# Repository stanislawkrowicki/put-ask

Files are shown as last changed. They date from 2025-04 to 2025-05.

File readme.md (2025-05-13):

# 🛠️ PepeBoy

**Portable GameBoy style console. Based on ESP32 microprocessor, 2.8" TFT display, WiFi** 

---

## 📌 Table of Contents
- [🎯 Project Goal](#-project-goal)
- [🔧 Hardware Design](#-hardware-design)
- [💻 Usage](#-usage)
- [🔧 Execution REV1](#-execution)

---

## 🎯 Project Goal

Portable and pocket size console, able to load games from external sd card. Possibility of on-line gameplay via Wi-Fi. Custom PCB board, self-made using CNC milling and UV solder mask paint; 3D printed case.

## 🔧 Hardware Design
The PCB was designed to be produced using a double-sided FR4 PCB blank. Unfortunately, due to the process, every via had to be soldered using copper wire. 

### ESP32 pinout description
#### buttons 
| Button | Switch id | GPIO  |
|:---:|:---:|:-----:|
| Right Button| SW_7 | IO35  |
| Left Button | SW_5 | IO27  |
| Up Button | SW_4 | IO33  |
| Down Button | SW_6 | IO34  |
| A Button | SW_8 | IO14  |
| B Button | SW_3 | IO32  |

#### touch 

| Touch Signal  | Description | GPIO  |
|:---:|:---:|:-----:|
| MISO | Master In Slave Out | IO19  |
| MOSI | Master Out Slave In | IO23  |
| CLK | Clock | IO18  |
| CS_T | Chip Select | IO4 |
| T_IRQ | Interrupt Handling | IO13  |

#### display
| Display Signal | GPIO  | Description |
|:---:|:-----:|:---:|
| SPI_CS | IO21  | Display Chip Select |
| SPI_MOSI | IO23  | Master Out Slave In (data) |
| SPI_MISO | IO19  | Master In Slave Out (data) |
| SPI_CLK | IO18  | Clock signal |
| D_DC | IO16  | Data/Command control |
| D_RST | IO17  | Display reset signal |
| D_LED | IO22  | Display backlight control |
#### SD card

| SD Signal  | GPIO  | Description |
|:---:|:-----:|:---:|
| SD_CS | IO25  | Chip Select karty SD |
| SD_CLK | IO18  | Clock signal |
| SD_MISO | IO19  | Master In Slave Out (data)  |
| SD_MOSI | IO23  | Master Out Slave In (data)  |

#### onePixel 2x2 led matrix
|2x2 LED signal|GPIO|Description|
|:--:|:--:|:--:|
|LED_DIN| IO26|Data in|

####  general SPI
| SPI Signal | GPIO  |
|:---:|:-----:|
| MISO | IO19  |
| MOSI | IO23  |
| CLK | IO18  |

<p align="center">
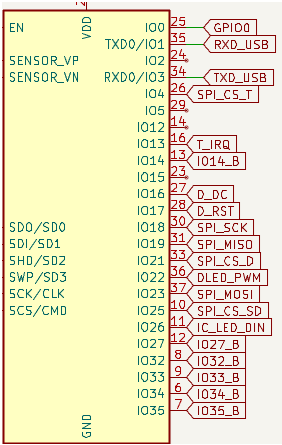
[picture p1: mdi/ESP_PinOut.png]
ESP pinout form KiCad
  
</p>
<!-- <p align="center">
  <img src="mdi/schem_all.jpg" alt="schematic of all" width="1000">
</p> -->

### Power Management Unit (IP5306) 
#### read execution paragraph !!!!
The console can be powered remotely using, for example, a 18650 Li-ion battery. Plugging the console into external power through USB-C will power the device and charge the battery. The IP5306 is used according to the typical application from the [datasheet](https://www.datasheetcafe.com/wp-content/uploads/2020/07/IP5306.pdf). We used a one-LED configuration and skipped the KEY_LED (D5 on the datasheet).

<p align="center">
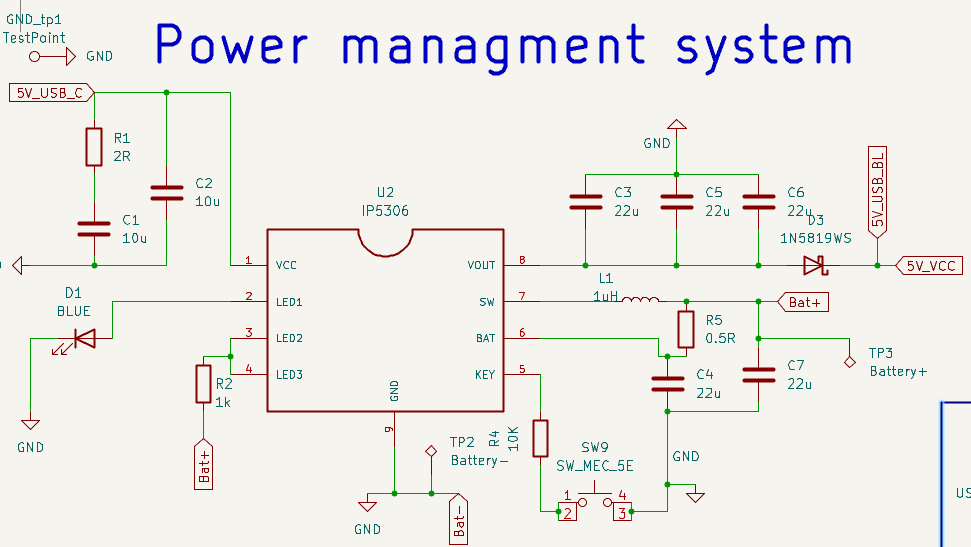
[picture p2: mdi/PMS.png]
  
</p>

## 💻 Usage

Description of how to use the project, e.g., how to start it, available modes, etc.

## 🔧 Execution
The PCB has been *mostly* successfully produced. We will leave a few notes describing our conclusions about what went wrong and what met or exceeded our expectations.

- Power Management Unit Failure: To be honest, I still don’t know exactly what went wrong. The design followed the datasheet, but the IC consistently failed, producing enough heat to desolder itself. After several attempts and considering the project deadline, I abandoned the idea of a remote power supply. If I were to do this again, I’d design a separate board dedicated solely to power management.

- Input-Only Pins (IO35, IO34): These pins lack internal pull-up resistors, and I neglected to include external ones in the design.

- WS2812 Segment Issue: This one’s due to a simple oversight: the collector of the Q1 transistor isn’t pulled up to 5V, which prevents proper operation of the LED segment.

- USB-C Port Soldering Difficulty: The mounting pads for the USB-C connector are too small, making the socket difficult to solder reliably. Larger pads would have made assembly easier.

---

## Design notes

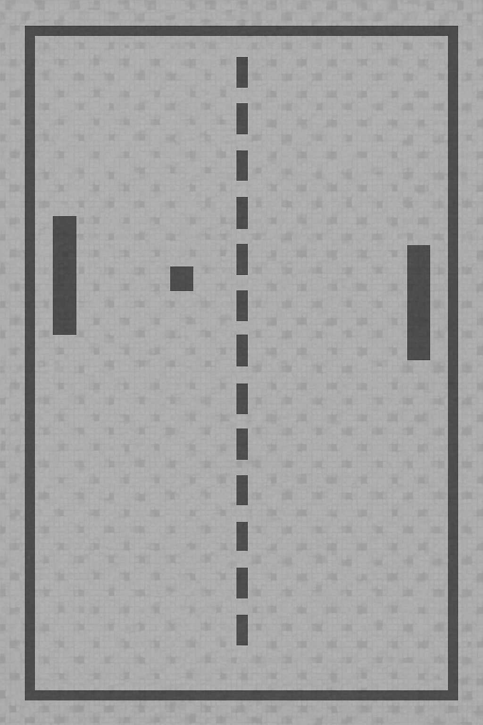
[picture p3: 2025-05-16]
pepelauncher/web/img/games/example.png

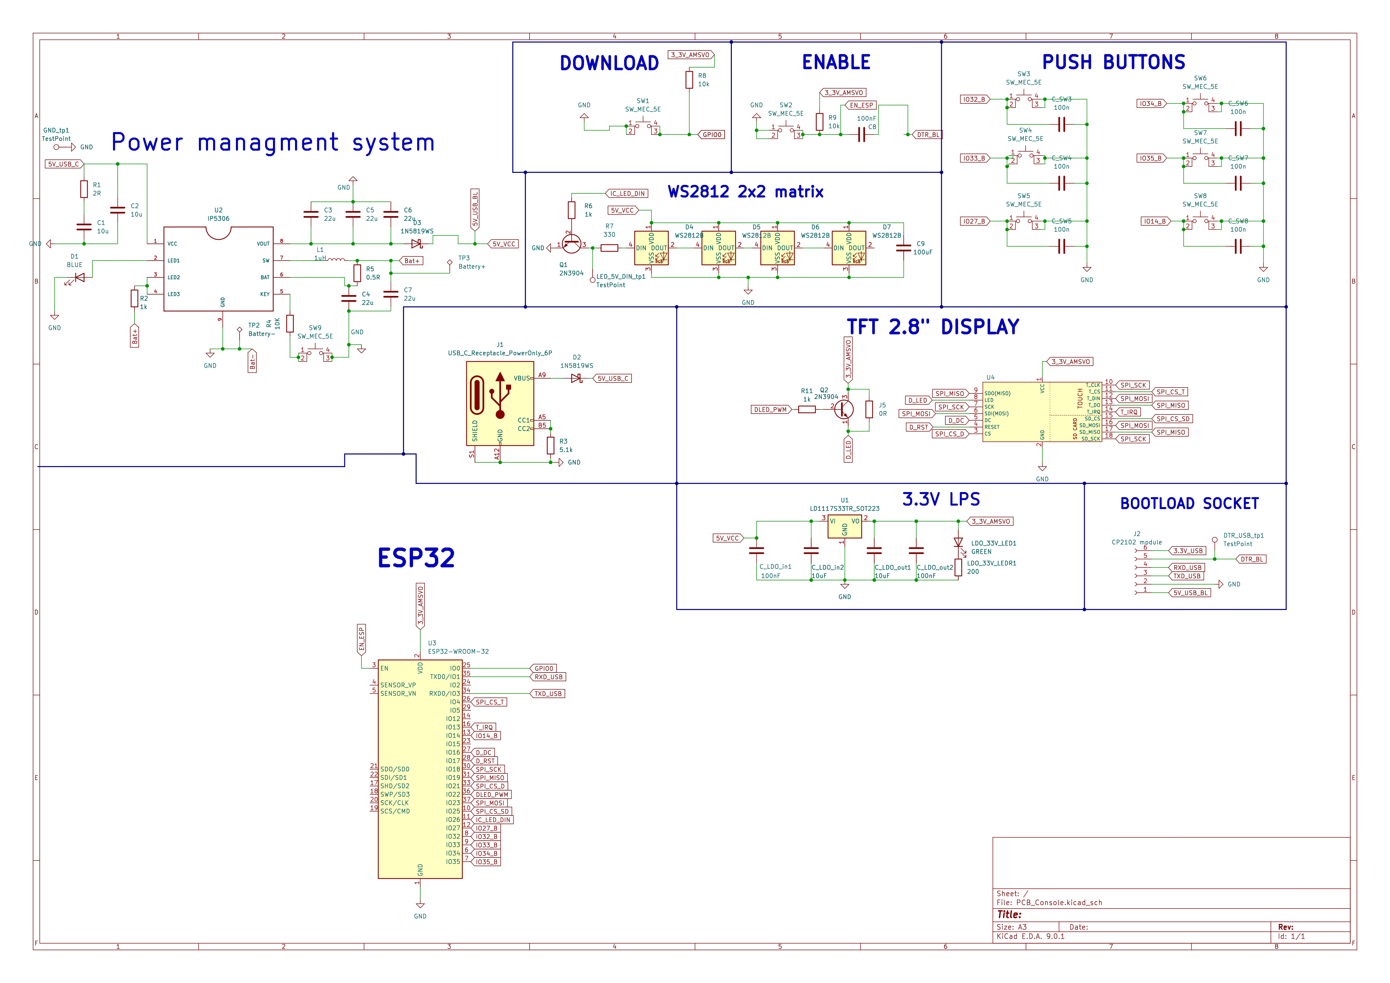
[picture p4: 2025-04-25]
mdi/schem_all.jpg

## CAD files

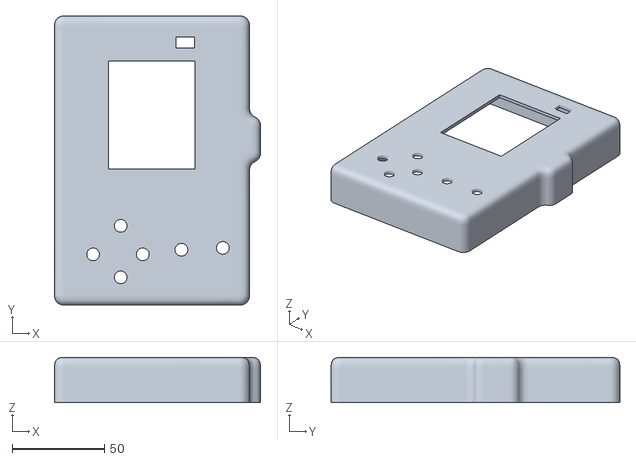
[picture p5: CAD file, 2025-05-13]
hardware/case/top_and_sides.stl
112.0 x 157.0 x 24.7

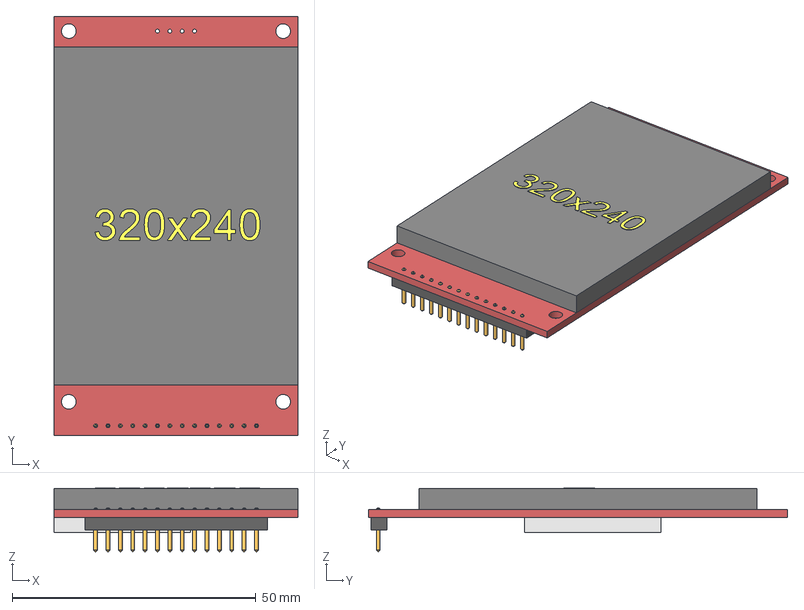
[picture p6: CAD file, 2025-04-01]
hardware/components_lib/TFT_320x240_touch_r0.step
50.0 x 86.0 x 13.1 mm
Body-header
Body-pins
Body-display
Body-sdcard
Body-board

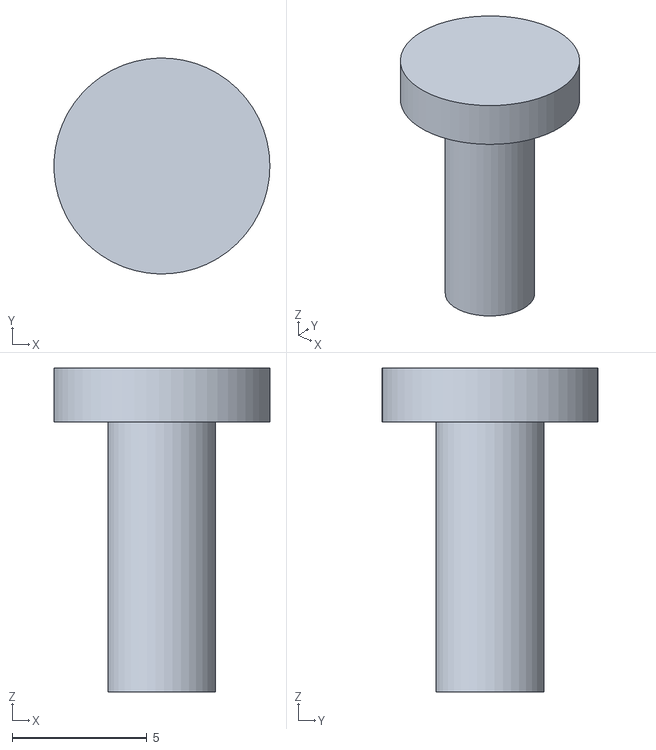
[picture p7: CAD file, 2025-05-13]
hardware/case/KeyCap.stl
7.99 x 8.00 x 12.0

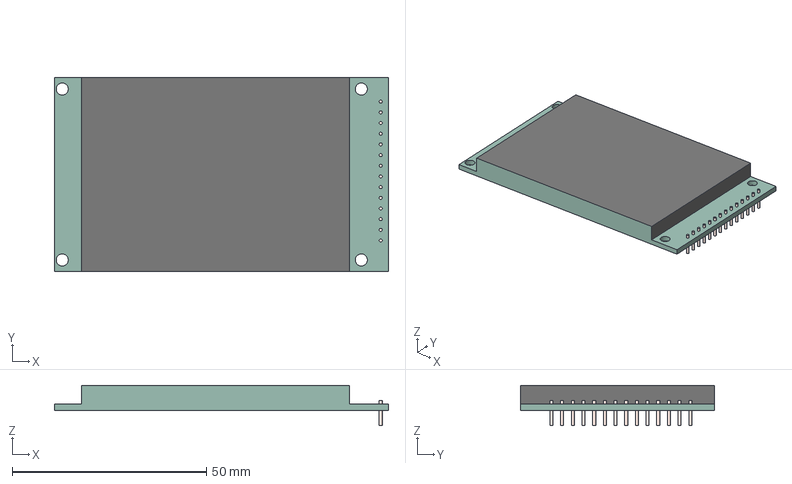
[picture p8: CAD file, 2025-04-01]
hardware/components_lib/TFT ILI9341.step
86.0 x 50.0 x 10.3 mm

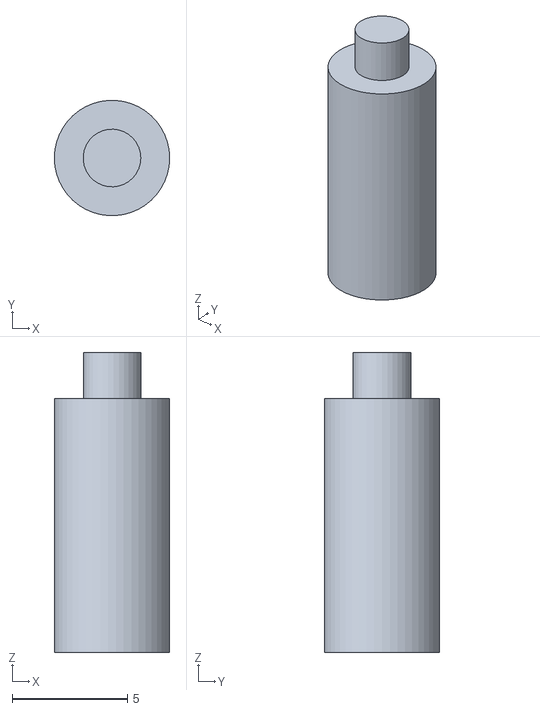
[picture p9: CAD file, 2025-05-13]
hardware/case/TFT_support.stl
5.00 x 4.99 x 13.0

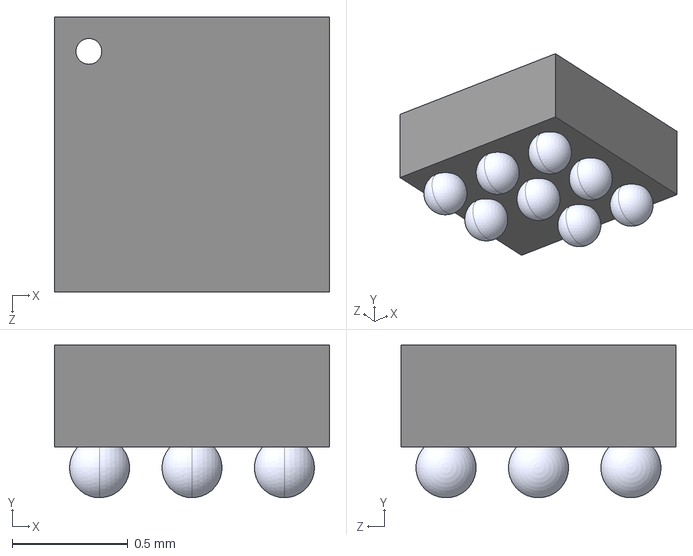
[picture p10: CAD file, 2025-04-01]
hardware/components_lib/IP5306.step
1.19 x 0.66 x 1.19 mm

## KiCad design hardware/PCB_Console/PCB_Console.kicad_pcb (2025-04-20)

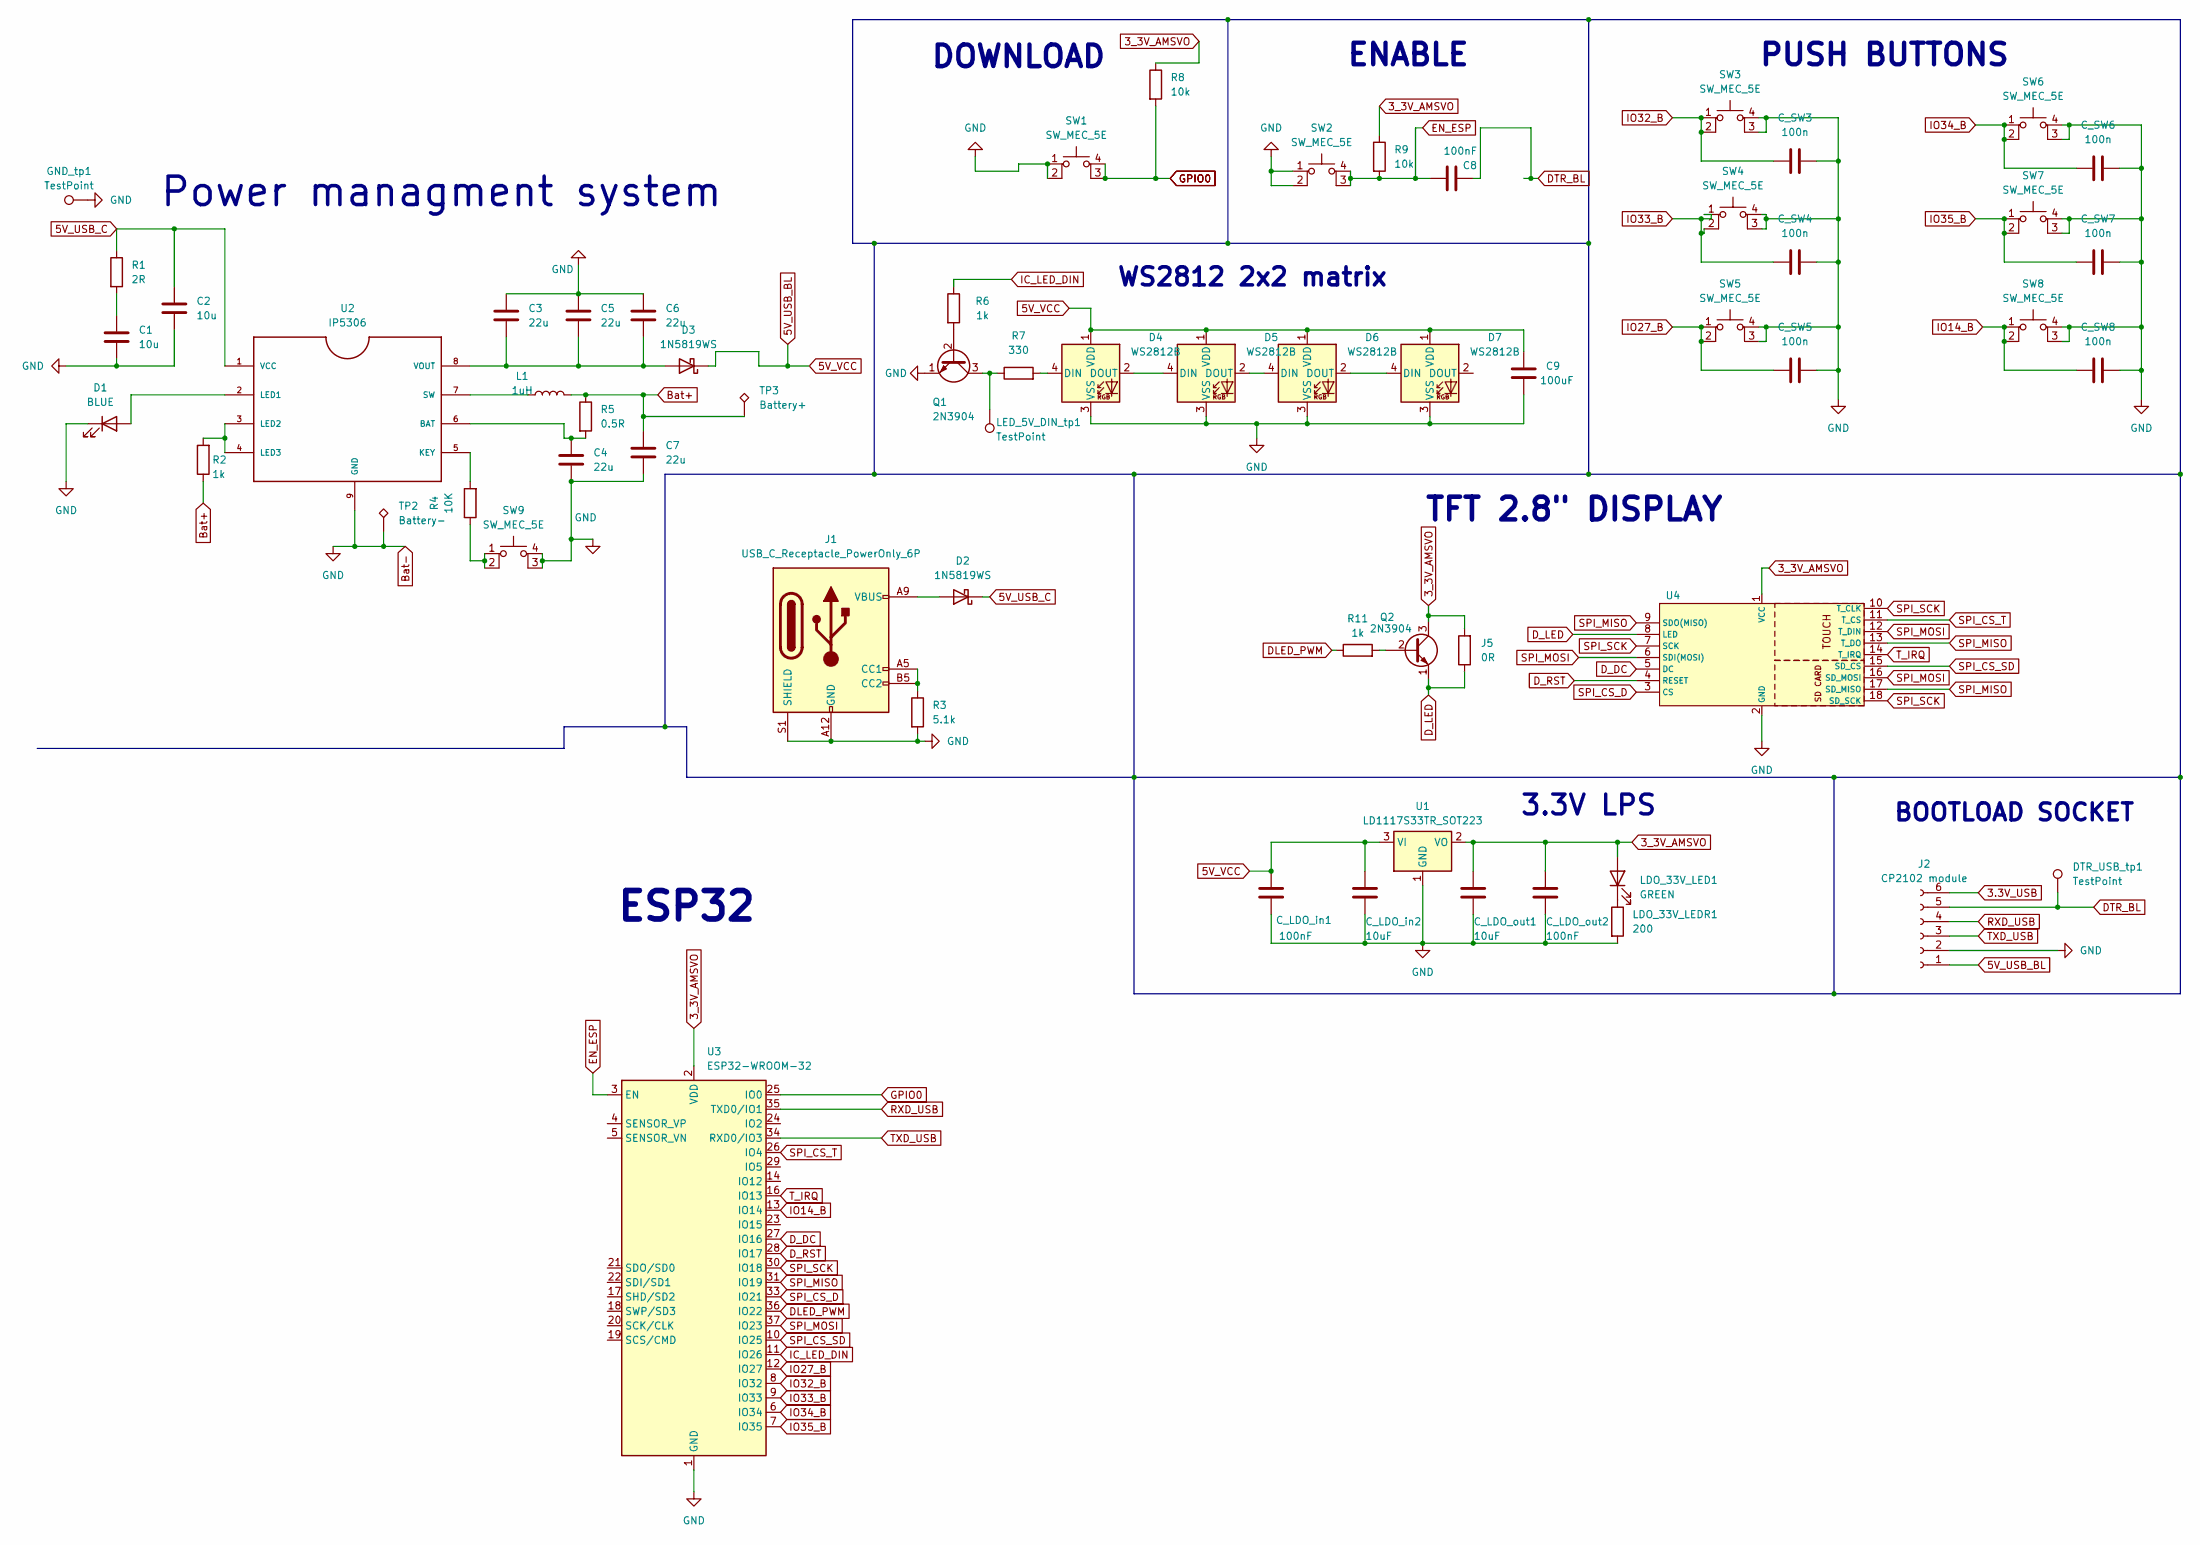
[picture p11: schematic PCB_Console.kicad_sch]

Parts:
C1, C2: 10u; C_1206_3216Metric_Pad1.33x1.80mm_HandSolder
C3, C4, C5, C6, C7: 22u; C_1206_3216Metric_Pad1.33x1.80mm_HandSolder
C8: 100nF; C_1206_3216Metric_Pad1.33x1.80mm_HandSolder
C9: 100uF; C_1206_3216Metric_Pad1.33x1.80mm_HandSolder
C_LDO_in1: 100nF; C_1206_3216Metric_Pad1.33x1.80mm_HandSolder
C_LDO_in2: 10uF; C_1206_3216Metric_Pad1.33x1.80mm_HandSolder
C_LDO_out1: 10uF; C_1206_3216Metric_Pad1.33x1.80mm_HandSolder
C_LDO_out2: 100nF; C_1206_3216Metric_Pad1.33x1.80mm_HandSolder
C_SW3, C_SW4, C_SW5, C_SW6, C_SW7, C_SW8: 100n; C_1206_3216Metric_Pad1.33x1.80mm_HandSolder
D1: BLUE; LED_D5.0mm
D2, D3: 1N5819WS; D_0805_2012Metric_Pad1.15x1.40mm_HandSolder
D4, D5, D6, D7: WS2812B; LED_WS2812B_PLCC4_5.0x5.0mm_P3.2mm
DTR_USB_tp1: TestPoint; TestPoint_Pad_D1.0mm
GND_tp1: TestPoint; TestPoint_Pad_D1.5mm
J1: USB_C_Receptacle_PowerOnly_6P; USB_C_Receptacle_GCT_USB4125-xx-x-0190_6P_TopMnt_Horizontal
J2: CP2102 module; PinSocket_1x06_P2.54mm_Vertical
J5: 0R; R_1206_3216Metric_Pad1.30x1.75mm_HandSolder
L1: 1uH; L_Chilisin_BMRB00060650
LDO_33V_LED1: GREEN; LED_D3.0mm
LDO_33V_LEDR1: 200; R_1206_3216Metric_Pad1.30x1.75mm_HandSolder
LED_5V_DIN_tp1: TestPoint; TestPoint_Pad_D1.0mm
Q1, Q2: 2N3904; TO-92_Wide
R1: 2R; R_1206_3216Metric_Pad1.30x1.75mm_HandSolder
R2, R6, R11: 1k; R_1206_3216Metric_Pad1.30x1.75mm_HandSolder
R3: 5.1k; R_1206_3216Metric_Pad1.30x1.75mm_HandSolder
R4: 10K; R_1206_3216Metric_Pad1.30x1.75mm_HandSolder
R5: 0.5R; R_1206_3216Metric_Pad1.30x1.75mm_HandSolder
R7: 330; R_1206_3216Metric_Pad1.30x1.75mm_HandSolder
R8, R9: 10k; R_1206_3216Metric_Pad1.30x1.75mm_HandSolder
SW1, SW2, SW9: SW_MEC_5E; SW_TS04-66-95-BK-100-SMT
SW3, SW4, SW5, SW6, SW7, SW8: SW_MEC_5E; SW_Push_12x12_aliexpress
TP2: Battery-; TestPoint_THTPad_D1.5mm_Drill0.7mm
TP3: Battery+; TestPoint_THTPad_D1.5mm_Drill0.7mm
U1: LD1117S33TR_SOT223; SOT-223-3_TabPin2
U2: IP5306; SOIC9P127_490X600X170L84X42T330X241N
U3: ESP32-WROOM-32
U4: TFT ILI9341

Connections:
3.3V_USB: J2.6
3_3V_AMSVO: C_LDO_out1.1, C_LDO_out2.1, J5.2, LDO_33V_LED1.2 (A), Q2.3 (C), R8.1, R9.1, U1.2 (VO), U3.2 (VDD), U4.1 (VCC)
5V_USB_BL: C9.2, C_LDO_in1.1, C_LDO_in2.1, D3.1 (K), D4.1 (VDD), D5.1 (VDD), D6.1 (VDD), D7.1 (VDD), J2.1, U1.3 (VI)
5V_USB_C: C2.1, D2.1 (K), R1.1, U2.1 (VCC)
Bat+: C7.1, L1.2, R2.1, R5.1, TP3.1
Bat-: C1.2, C2.2, C3.1, C4.2, C5.1, C6.1, C7.2, C9.1, C_LDO_in1.2, C_LDO_in2.2, C_LDO_out1.2, C_LDO_out2.2, C_SW3.1, C_SW4.1, C_SW5.1, C_SW6.1, C_SW7.1, C_SW8.1, D1.1 (K), D4.3 (VSS), D5.3 (VSS), D6.3 (VSS), D7.3 (VSS), GND_tp1.1, J1.A12 (GND), J1.B12 (GND), J1.S1 (SHIELD), J2.2, LDO_33V_LEDR1.2, Q1.1 (E), R3.2, SW1.1, SW1.2, SW2.1, SW2.2, SW3.3 (K), SW3.4 (A), SW4.3 (K), SW4.4 (A), SW5.3 (K), SW5.4 (A), SW6.3 (K), SW6.4 (A), SW7.3 (K), SW7.4 (A), SW8.3 (K), SW8.4 (A), SW9.3 (K), SW9.4 (A), TP2.1, U1.1 (GND), U2.9 (GND), U3.1 (GND), U3.15 (GND), U3.38 (GND), U3.39 (GND), U4.2 (GND)
DLED_PWM: R11.1, U3.36 (IO22)
DTR_BL: C8.2, DTR_USB_tp1.1, J2.5
D_DC: U3.27 (IO16), U4.5 (DC)
D_LED: J5.1, Q2.1 (E), U4.8 (LED)
D_RST: U3.28 (IO17), U4.4 (RESET)
EN_ESP: C8.1, R9.2, SW2.3 (K), SW2.4 (A), U3.3 (EN)
GPIO0: R8.2, SW1.3 (K), SW1.4 (A), U3.25 (IO0)
IC_LED_DIN: R6.1, U3.11 (IO26)
IO14_B: C_SW8.2, SW8.1, SW8.2, U3.13 (IO14)
IO27_B: C_SW5.2, SW5.1, SW5.2, U3.12 (IO27)
IO32_B: C_SW3.2, SW3.1, SW3.2, U3.8 (IO32)
IO33_B: C_SW4.2, SW4.1, SW4.2, U3.9 (IO33)
IO34_B: C_SW6.2, SW6.1, SW6.2, U3.6 (IO34)
IO35_B: C_SW7.2, SW7.1, SW7.2, U3.7 (IO35)
unnamed: C1.1, R1.2
unnamed: D1.2 (A), U2.2 (LED1)
unnamed: D2.2 (A), J1.A9 (VBUS), J1.B9 (VBUS)
unnamed: C3.2, C5.2, C6.2, D3.2 (A), U2.8 (VOUT)
unnamed: D4.4 (DIN), R7.2
unnamed: D4.2 (DOUT), D5.4 (DIN)
unnamed: D5.2 (DOUT), D6.4 (DIN)
unnamed: D6.2 (DOUT), D7.4 (DIN)
unnamed: J1.A5 (CC1), J1.B5 (CC2), R3.1
unnamed: LDO_33V_LED1.1 (K), LDO_33V_LEDR1.1
unnamed: Q1.2 (B), R6.2
unnamed: LED_5V_DIN_tp1.1, Q1.3 (C), R7.1
unnamed: Q2.2 (B), R11.2
unnamed: R4.1, SW9.1, SW9.2
unnamed: C4.1, R5.2, U2.6 (BAT)
unnamed: R4.2, U2.5 (KEY)
unnamed: R2.2, U2.3 (LED2), U2.4 (LED3)
unnamed: L1.1, U2.7 (SW)
RXD_USB: J2.4, U3.35 (TXD0/IO1)
SPI_CS_D: U3.33 (IO21), U4.3 (CS)
SPI_CS_SD: U3.10 (IO25), U4.15 (SD_CS)
SPI_CS_T: U3.26 (IO4), U4.11 (T_CS)
SPI_MISO: U3.31 (IO19), U4.9 (SDO(MISO)), U4.13 (T_DO), U4.17 (SD_MISO)
SPI_MOSI: U3.37 (IO23), U4.6 (SDI(MOSI)), U4.12 (T_DIN), U4.16 (SD_MOSI)
SPI_SCK: U3.30 (IO18), U4.7 (SCK), U4.10 (T_CLK), U4.18 (SD_SCK)
TXD_USB: J2.3, U3.34 (RXD0/IO3)
T_IRQ: U3.16 (IO13), U4.14 (T_IRQ)

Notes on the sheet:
ESP32
PUSH BUTTONS
Power managment system
BOOTLOAD SOCKET
3.3V LPS
TFT 2.8" DISPLAY
DOWNLOAD
WS2812 2x2 matrix
ENABLE

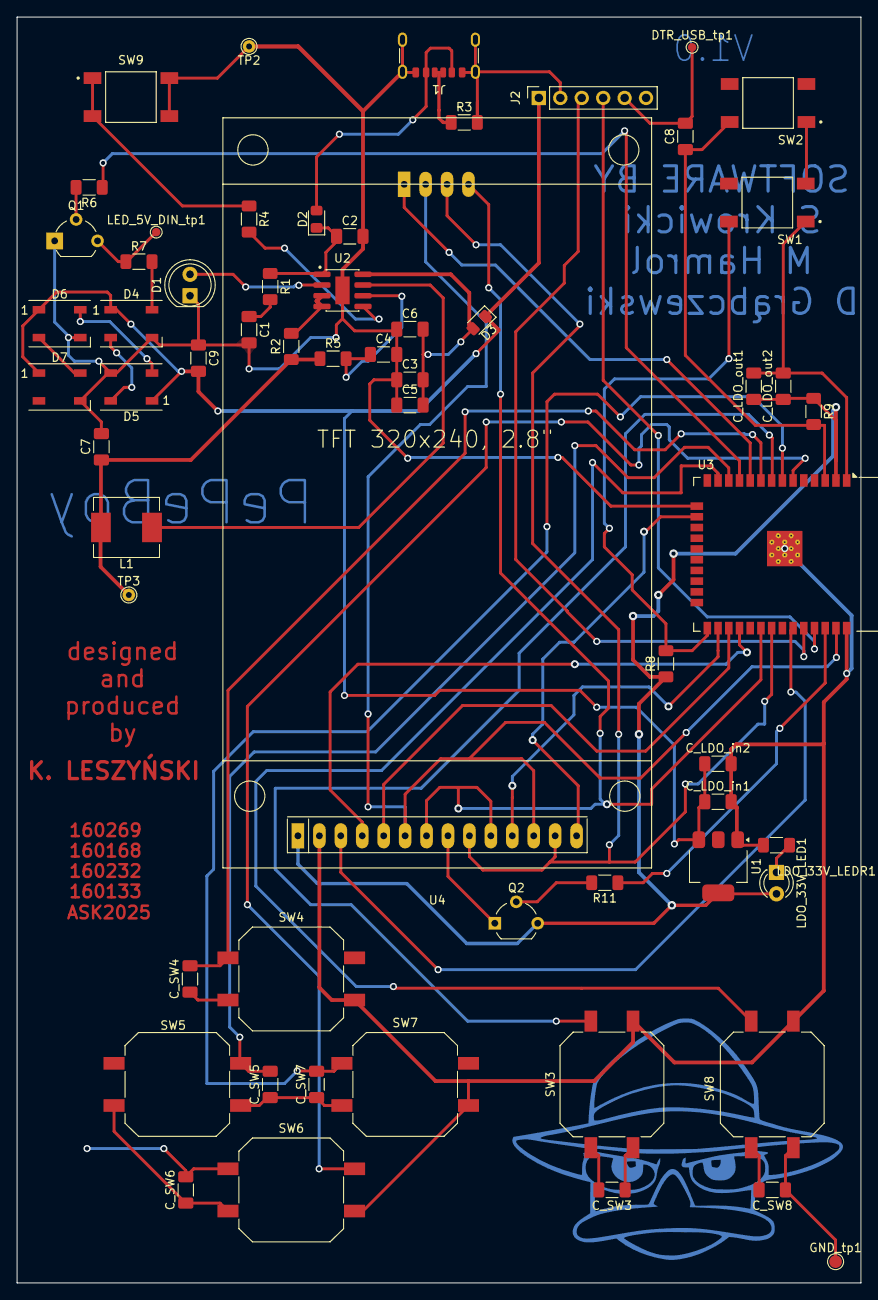
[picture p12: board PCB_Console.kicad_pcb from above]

Board: 2 copper layers, 100.0 x 150.0 mm, 61 parts (0 on the bottom side), 46 nets.

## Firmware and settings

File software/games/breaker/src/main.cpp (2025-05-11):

#include <Arduino.h>
#include <WiFi.h>
#include <TFT_eSPI.h>

#include <OTAServer.h>
#include "wifi_secrets.h"

#define BTN_LEFT 27
#define BTN_RIGHT 35

#define COLOR_1 TFT_BLUE    
#define COLOR_2 TFT_YELLOW   
#define COLOR_3 TFT_GREEN 

OTAServer otaServer;
TFT_eSPI tft = TFT_eSPI();




//breaker constants

const int SCREEN_WIDTH = 240;
const int SCREEN_HEIGHT = 320;

const int rows = 6;
const int cols = 8;
const int blockWidth = 26;
const int blockHeight = 10;

bool blocks[rows][cols];
int blockPosX[cols];
int blockPosY[rows];

int blockPoints[rows][cols] = {
  {10, 20, 30, 20, 10, 20, 30, 20},  
  {20, 10, 20, 30, 20, 10, 20, 30},  
  {30, 20, 10, 20, 30, 20, 10, 20},  
  {20, 30, 20, 10, 20, 30, 20, 10},  
  {10, 20, 30, 20, 10, 20, 30, 20},  
  {20, 10, 20, 30, 20, 10, 20, 30}  
};


uint16_t blockColors[rows][cols] = {
  {COLOR_1, COLOR_2, COLOR_3, COLOR_1, COLOR_2, COLOR_3, COLOR_1, COLOR_2},
  {COLOR_2, COLOR_3, COLOR_1, COLOR_2, COLOR_3, COLOR_1, COLOR_2, COLOR_3},
  {COLOR_3, COLOR_1, COLOR_2, COLOR_3, COLOR_1, COLOR_2, COLOR_3, COLOR_1},
  {COLOR_1, COLOR_2, COLOR_3, COLOR_1, COLOR_2, COLOR_3, COLOR_1, COLOR_2},
  {COLOR_2, COLOR_3, COLOR_1, COLOR_2, COLOR_3, COLOR_1, COLOR_2, COLOR_3},
  {COLOR_3, COLOR_1, COLOR_2, COLOR_3, COLOR_1, COLOR_2, COLOR_3, COLOR_1}
};

int platform_level = 270;
int platformX = 100;
float ballX = 120.0;
float ballY = 200.0;
float ballDx = 1.0;
float ballDy = -1.0;
int ballSize = 4;
int yJoyStick = 0;
float ballSpeed = 5.0;
bool game_over = false;
bool win = false;
float maxSpeed = 40.0;
int score=0;

void setup_blocks() {
  for (int i = 0; i < rows; i++) {
    blockPosY[i] = 20 + i * (blockHeight + 4);
    for (int j = 0; j < cols; j++) {
      if (i == 0) blockPosX[j] = 5 + j * (blockWidth + 4);
      blocks[i][j] = true;
    }
  }
}

void setup()
{
  Serial.begin(115200);
  WiFi.begin(WIFI_SSID, WIFI_PASSWORD);

  while (WiFi.status() != WL_CONNECTED)
  {
    delay(500);
    Serial.print(".");
  }
  Serial.println("WiFi connected");

  otaServer.enable();

  pinMode(22, OUTPUT);
  digitalWrite(22, HIGH);

  pinMode(BTN_LEFT, INPUT_PULLUP);
  pinMode(BTN_RIGHT, INPUT_PULLUP);

  tft.init();
  tft.fillScreen(TFT_BLACK);
  tft.setTextColor(TFT_WHITE);
  tft.setTextSize(2);
  tft.setCursor(20, 100);
  tft.println("BREAKER");
  delay(2000);
  tft.fillScreen(TFT_BLACK);

  setup_blocks();
}

void check_win() {
  win = true;
  for(int i=0; i<rows; i++) {
    for(int j=0; j<cols; j++) {
      if(blocks[i][j]) {
        win = false;
        return;
      }
    }
  }
}

void ball_movement() {
  ballX += ballDx;
  ballY += ballDy;

  if(ballX - ballSize <= 0 || ballX + ballSize >= SCREEN_WIDTH) ballDx = -ballDx;
  if(ballY - ballSize <= 0) ballDy = -ballDy;

  if(ballY + ballSize >= platform_level && ballY + ballSize <= platform_level + 4 &&
     ballX >= platformX && ballX <= platformX + 40) {
    ballDy = -abs(ballDy);
    ballY = platform_level - ballSize;
    if (ballSpeed < maxSpeed) {
      ballSpeed += 0.2;
    }
  }

  if(ballY + ballSize > SCREEN_HEIGHT) game_over = true;

  // Speed limit
  if(ballDx > maxSpeed) ballDx = maxSpeed;
  if(ballDx < -maxSpeed) ballDx = -maxSpeed;
  if(ballDy > maxSpeed) ballDy = maxSpeed;
  if(ballDy < -maxSpeed) ballDy = -maxSpeed;
  float angle = atan2(ballDy, ballDx);
  ballDx = cos(angle) * ballSpeed;
  ballDy = sin(angle) * ballSpeed;
}

void check_block_collision() {
  for (int i = 0; i < rows; i++) {
    for (int j = 0; j < cols; j++) {
      if (blocks[i][j]) {
        int bx = blockPosX[j];
        int by = blockPosY[i];

        if (ballX + ballSize >= bx && ballX - ballSize <= bx + blockWidth &&
            ballY + ballSize >= by && ballY - ballSize <= by + blockHeight) {
          blocks[i][j] = false;
          ballDy = -ballDy;
          score += blockPoints[i][j];
          if (ballSpeed < maxSpeed) {
            ballSpeed += 0.1;
          }
          return;
        }
      }
    }
  }
}

void draw_blocks() {
  for (int i = 0; i < rows; i++) {
    for (int j = 0; j < cols; j++) {
      if (blocks[i][j]) {
        tft.fillRect(blockPosX[j], blockPosY[i], blockWidth, blockHeight, blockColors[i][j]);
      } else {
        tft.fillRect(blockPosX[j], blockPosY[i], blockWidth, blockHeight, TFT_BLACK);
      }
    }
  }
}

void draw_scene() {
  tft.fillRect(platformX, platform_level, 40, 4, TFT_WHITE);
  tft.fillCircle((int)ballX, (int)ballY, ballSize, TFT_RED);
}

void draw_score() {
  tft.setTextColor(TFT_WHITE, TFT_BLACK);
  tft.setTextSize(2);
  tft.setCursor(10, SCREEN_HEIGHT - 20);
  tft.print("Score: ");
  tft.print(score);
}

void button_reaction() {
  if (digitalRead(BTN_RIGHT) == LOW && platformX + 40 < SCREEN_WIDTH) {
    platformX += 5;
  }
  if (digitalRead(BTN_LEFT) == LOW && platformX > 0) {
    platformX -= 5;
  }
}
void check_restart() {
  if (digitalRead(BTN_LEFT) == LOW && digitalRead(BTN_RIGHT) == LOW) {
    game_over = false;
    score=0;
    win = false;
    ballX = 120.0;
    ballY = 200.0;
    ballDx = 1.0;
    ballDy = -1.0;
    platformX = 100;
    ballSpeed=5.0;
    setup_blocks();
    tft.fillScreen(TFT_BLACK);
  }
}
void erase_previous(float prevBallX, float prevBallY, int prevPlatformX) {
  tft.fillRect(prevPlatformX, platform_level, 40, 4, TFT_BLACK);       
  tft.fillCircle((int)prevBallX, (int)prevBallY, ballSize, TFT_BLACK);
  tft.fillRect(10, SCREEN_HEIGHT - 20, 120, 16, TFT_BLACK);
}

void draw_game_over() {
  tft.fillScreen(TFT_BLACK);
  tft.setTextColor(TFT_RED);
  tft.setTextSize(3);
  tft.setCursor(50, 120);
  tft.print("GAME OVER");

  tft.setTextColor(TFT_WHITE);
  tft.setTextSize(2);
  tft.setCursor(60, 170);
  tft.print("Score: ");
  tft.print(score);
}

void draw_win() {
  tft.fillScreen(TFT_BLACK);
  tft.setTextColor(TFT_GREEN);
  tft.setTextSize(3);
  tft.setCursor(60, 140);
  tft.print("YOU WIN!");
}

void loop() {
  static float prevBallX = ballX;
  static float prevBallY = ballY;
  static int prevPlatformX = platformX;

  if (!game_over && !win) {
    erase_previous(prevBallX, prevBallY, prevPlatformX);
    button_reaction();
    ball_movement();
    check_block_collision();
    check_win();
    draw_blocks();
    draw_scene();
    draw_score();

    prevBallX = ballX;
    prevBallY = ballY;
    prevPlatformX = platformX;

  } else if (game_over) {
    draw_game_over();
    check_restart();
    delay(100);
  } else if (win) {
    draw_win();
    check_restart();
    delay(100);
  }

  delay(20);
  otaServer.handleHttpClient();
  otaServer.handleDiscoveries();
}

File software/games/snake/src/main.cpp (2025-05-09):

#include <Arduino.h>
#include <WiFi.h>
#include <TFT_eSPI.h>

#include <OTAServer.h>
#include "wifi_secrets.h"

#define BTN_UP 16
#define BTN_DOWN 17
#define BTN_LEFT 18
#define BTN_RIGHT 19

OTAServer otaServer;
TFT_eSPI tft = TFT_eSPI();


//snake globals

int direction = 4; // 0=up, 1=down, 2=right, 3=left
bool in_boarder = true;
bool colision = false;
bool is_apple = false;

#define SNAKE_MAX 60
int snakeX[SNAKE_MAX] = {40};
int snakeY[SNAKE_MAX] = {30};
int prevSnakeX[SNAKE_MAX];
int prevSnakeY[SNAKE_MAX];
int snakeLength = 1;
int appleX, appleY;
int rockX,rockY;
bool rock_active = false;
unsigned long rock_spawn_time = 0;
int rock_time = 5000;
int rock_interval = 7000;
unsigned long last_rock_spawn = 0;

int score = 0;
int game_speed = 150;
int last_score_for_speed = -2;

bool game_over_flag = false;

void setup()
{
  Serial.begin(115200);
  pinMode(BTN_UP, INPUT_PULLUP);
  pinMode(BTN_DOWN, INPUT_PULLUP);
  pinMode(BTN_LEFT, INPUT_PULLUP);
  pinMode(BTN_RIGHT, INPUT_PULLUP);
  WiFi.begin(WIFI_SSID, WIFI_PASSWORD);

  // while (WiFi.status() != WL_CONNECTED)
  // {
  //   delay(500);
  //   Serial.print(".");
  // }
  Serial.println("WiFi connected");

  otaServer.enable();

  pinMode(21, OUTPUT);
  digitalWrite(21, HIGH);
  
  //tft.init();
  //tft.fillScreen(TFT_RED);
  //tft.setCursor(0,0,4);
  //tft.setTextColor(TFT_BLACK);
  //tft.println ("Hello World!");

  tft.init();
  tft.fillScreen(TFT_DARKCYAN);

  tft.setTextColor(TFT_WHITE);
  tft.setTextSize(2);
  tft.setCursor(20, 100);
  tft.println("SNAKE GAME");
  delay(2000);
  tft.fillScreen(TFT_DARKCYAN);



  
}

void draw_score() {
  // tft.fillRect(0, 0, 80, 16, TFT_DARKCYAN);

  tft.setCursor(0, 0);
  tft.setTextColor(TFT_YELLOW);
  tft.setTextSize(2);
  tft.print("Score: ");
  tft.print(score);
}

void handle_buttons() {
  if (digitalRead(BTN_UP) == LOW && direction!=1) direction = 0;
  if (digitalRead(BTN_DOWN) == LOW && direction!=0) direction = 1;
  if (digitalRead(BTN_RIGHT) == LOW && direction!=3) direction = 2;
  if (digitalRead(BTN_LEFT) == LOW && direction!=2) direction = 3;
}

void move_snake() {

  for (int i = 0; i < snakeLength; i++) {
    prevSnakeX[i] = snakeX[i];
    prevSnakeY[i] = snakeY[i];
  }

  for (int i = snakeLength - 1; i > 0; i--) {
    snakeX[i] = snakeX[i - 1];
    snakeY[i] = snakeY[i - 1];
  }

  switch (direction) {
    case 0: snakeY[0] -= 8; break; // up
    case 1: snakeY[0] += 8; break; // down
    case 2: snakeX[0] += 8; break; // right
    case 3: snakeX[0] -= 8; break; // left
  }
}

void draw_snake() {
  for (int i = 0; i < snakeLength; i++) {
    tft.fillRect(prevSnakeX[i], prevSnakeY[i], 8, 8, TFT_DARKCYAN);
    tft.fillRect(snakeX[i], snakeY[i], 8, 8, TFT_GREEN);
    
  }
}

void draw_apple() {
  if (!is_apple) {
    bool valid = false;

    while (!valid) {
      appleX = random(2, 29) * 8;
      appleY = random(2, 28) * 8;
      valid = true;

      for (int i = 0; i < snakeLength; i++) {
        if (snakeX[i] == appleX && snakeY[i] == appleY) {
          valid = false;
          break;
        }
      }
    }

    is_apple = true;
  }

  tft.fillRect(appleX, appleY, 8, 8, TFT_RED);
}

void check_apple() {
  if (abs(snakeX[0] - appleX) < 8 && abs(snakeY[0] - appleY) < 8) {
    if (snakeLength < SNAKE_MAX) snakeLength++;
    is_apple = false;
    tft.fillRect(appleX, appleY, 8, 8, TFT_DARKCYAN);
    score++;
    tft.fillRect(50, 0,60 , 16, TFT_DARKCYAN);
    draw_score();
  }

  if (score % 2 == 0 && score != last_score_for_speed && game_speed > 50) {
    game_speed -= 10;
    last_score_for_speed = score;
  }

}

void check_collision() {
  if (snakeX[0] < 0 || snakeX[0] > 232 || snakeY[0] < 0 || snakeY[0] > 312) {
    in_boarder = false;
  }

  for (int i = 1; i < snakeLength; i++) {
    if (snakeX[0] == snakeX[i] && snakeY[0] == snakeY[i]) {
      colision = true;
    }
  }
}

void game_over() {
  tft.fillScreen(TFT_BLACK);
  tft.setCursor(40, 80);
  tft.setTextSize(2);
  tft.setTextColor(TFT_RED);
  tft.println("GAME OVER");
  
  tft.setCursor(40, 110);
  tft.setTextColor(TFT_WHITE);
  tft.print("Score: ");
  tft.println(score);

  tft.setCursor(20, 140);
  tft.println("Press any key");


  game_over_flag = true;
}
void draw_rock() {
  bool valid = false;
  while(!valid){
    rockX = random(2, 29) * 8;
    rockY = random(2, 28) * 8;
    valid = true;
    for(int i=0;i<snakeLength;i++){
      if((snakeX[i]==rockX && snakeY[i]==rockY)||(appleX==rockX && appleY==rockY)){
        valid = false;
        break;
      }
    }
  }
  tft.fillRect(rockX,rockY,12,12,TFT_BLACK);
  rock_active = true;
  rock_spawn_time = millis();
}

void handle_rock(){
  unsigned long current_time = millis();
  if(!rock_active && current_time - last_rock_spawn >= rock_interval){
    draw_rock();
    last_rock_spawn = current_time;
  }

  if(rock_active && current_time - last_rock_spawn >= rock_time){
    tft.fillRect(rockX,rockY,12,12,TFT_DARKCYAN);
    rock_active = false;
  }

  if (abs(snakeX[0] - rockX) < 12 && abs(snakeY[0] - rockY) < 12) {
    game_over();
  }
}
void reset_game() {
  direction = 4;
  in_boarder = true;
  colision = false;
  is_apple = false;
  score = 0;
  game_speed = 200;
  snakeLength = 1;
  snakeX[0] = 40;
  snakeY[0] = 30;
  game_over_flag = false;

  tft.fillScreen(TFT_DARKCYAN);
}

void loop()
{

  if (game_over_flag) {
    if (digitalRead(BTN_UP) == LOW || digitalRead(BTN_DOWN) == LOW || 
        digitalRead(BTN_LEFT) == LOW || digitalRead(BTN_RIGHT) == LOW) {
      reset_game();
    }
    delay(100);
    return;
  }

  if (!in_boarder || colision) {
    game_over();
    return;
  }

  // tft.fillScreen(TFT_DARKCYAN);
  handle_buttons();
  move_snake();
  draw_score();
  draw_apple();
  draw_snake();
  check_apple();
  handle_rock();
  check_collision();


  delay(game_speed);

  //if (digitalRead(BTN_UP) == LOW) Serial.println("Button 1 pressed");
  //if (digitalRead(BTN_DOWN) == LOW) Serial.println("Button 2 pressed");
  //if (digitalRead(BTN_LEFT) == LOW) Serial.println("Button 3 pressed");
  //if (digitalRead(BTN_RIGHT) == LOW) Serial.println("Button 4 pressed");
  //delay(100);
  otaServer.handleHttpClient();
  otaServer.handleDiscoveries();
}

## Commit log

2025-04-01 może tym razem wszystkiego niezepsuje?
    [IP5306.step, TFT ILI9341.step, TFT_320x240_touch_r0.step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]
2025-04-01 renamed kicad files
    [PCB_Console.kicad_pcb, PCB_Console.kicad_sch, bez ekranu.kicad_pcb]
2025-04-02 dodano przyciski, poprawione biblioteki
    [IP5306.step, PCB_Console.kicad_pcb, PCB_Console.kicad_sch]
2025-04-06 display connected to esp, pinout checked
    [PCB_Console.kicad_sch]
2025-04-06 deleted unnecessery back-ups; making schematic more modular, easier to read
    [PCB_Console.kicad_sch]
2025-04-13 zaczynam routing, zaczynam sie martwic ze ten projekt jest awykonalny w dostepnej technologi
    [PCB_Console.kicad_pcb]
2025-04-16 routing and placment, few edits on schematics
    [PCB_Console.kicad_pcb, PCB_Console.kicad_sch]
2025-04-16 routing next step
    [PCB_Console.kicad_pcb, PCB_Console.kicad_sch]
2025-04-17 routing czesc dalsza, power manager system wmiare polaczony
    [PCB_Console.kicad_pcb, PCB_Console.kicad_sch]
2025-04-20 routing on 2l done, need to check, text and logo added
    [PCB_Console.kicad_pcb, PCB_Console.kicad_sch]
2025-04-25 readme power system added
2025-04-29 Working OTA upload ESP32 firmware
2025-05-11 Update readme.md wrong pin number TFT SPI RST
2025-05-11 pinout fixed, now it is according to readme and PCB
    [main.cpp]
2025-05-13 case stl models added
    [KeyCap.stl, TFT_support.stl, top_and_sides.stl]
2025-05-16 pull up resistors added; level shifter fixed-> tested using sim LTspice
    [PCB_Console.kicad_sch]
